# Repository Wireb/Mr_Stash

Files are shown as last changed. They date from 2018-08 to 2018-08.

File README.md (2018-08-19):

# Mr Stash
Mr Stash was a badge I built for DC26 to use for trade of other badges and SAOs. 
License is MIT so do what you want with it just don't litigate me. 

**NOTE** I screwed up and wipped my laptop hard drive before pulling the final firmware version off it. The version in this repo is from right before I left for DC26 and is missing the following items:
- LED mode that cycles though all patterns
- Bonus hidden Morse code message at high pattern offset 
- All but one vibe pattern
- Vibe mode that cycles though all patterns once
- Updated touch sensor code. Code in repo works good in my house in MN but was unusable in the dry Nevada environment. 

## InkScape
Inkscape was used for the "art" layout of the badge. This mainly consisted of the outline, Stash, motors, IR sensor locations, and eyebrows. These layers were converted into SVG files then imported into KiCad as footprints. 
The edge cuts were post processed via Perl scripts to convert it from a filled zone (KiCad 3D viewer pukes on this) to line segments. 

## KiCad
This is a KiCad 4.x project that has been updated to 5.0 so some things are a little funky. 
Note the following parts were not populated in the final design: 1x 0.1uF cap, 4x 22uF cap, 2x diodes, 1x badge bus connector, 1x SAO connector 

## mplabX
This is a mplabX 4.2 project that was upgraded mid project to 5.0. All programming / debug was done with a PicKit4 or a PicKit3 (killed my PK4 just before leaving for DC26)
The firmware source is all contained in Mr_Stash.asm (see note above about missing functions)

## documentation
This is a XLS/PDF dump of the spreadsheet documentation I was using during development. 
All the menu items and command protocol are detailed in here. 

Copyright (c) 2018 Peter Shabino

Permission is hereby granted, free of charge, to any person obtaining a copy of this hardware, software, and associated documentation files 
(the "Product"), to deal in the Product without restriction, including without limitation the rights to use, copy, modify, merge, publish, 
distribute, sublicense, and/or sell copies of the Product, and to permit persons to whom the Product is furnished to do so, subject to the 
following conditions:

The above copyright notice and this permission notice shall be included in all copies or substantial portions of the Product.

THE PRODUCT IS PROVIDED "AS IS", WITHOUT WARRANTY OF ANY KIND, EXPRESS OR IMPLIED, INCLUDING BUT NOT LIMITED TO THE WARRANTIES OF 
MERCHANTABILITY, FITNESS FOR A PARTICULAR PURPOSE AND NONINFRINGEMENT. IN NO EVENT SHALL THE AUTHORS OR COPYRIGHT HOLDERS BE LIABLE 
FOR ANY CLAIM, DAMAGES OR OTHER LIABILITY, WHETHER IN AN ACTION OF CONTRACT, TORT OR OTHERWISE, ARISING FROM, OUT OF OR IN CONNECTION 
WITH THE PRODUCT OR THE USE OR OTHER DEALINGS IN THE PRODUCT.

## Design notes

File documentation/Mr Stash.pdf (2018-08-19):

Input voltage | 3V to 4.5V | 3 AA batteries
vibration motors | 2 | PWM 7 steps + off
IR coms | 1 Tx/Rx pair | 38kHz 8N1 2994 baud
RGB leds | 4 tripplets | 2 bit PWM per color + 2 bit blink per led
Shitty addon | 1 | Wired but not populated or used in current firmware
Badgebus | 1 | Wired but not populated or used in current firmware
Micro | 1 | PIC16F15355

55 | $10.03 | $551.68 < parts only see total below for other supplies
Item | price per unit | pcs per unit | Q | extended | link Pager motors | $23.88 | 100 | $0.24 | 2 | 2 | 110 | $0.48 PIC | $26.01 | 25 | $1.04 | 1 | 1 | 55 | $1.04 | https://www.digikey.com/product-detail/en/microchip-technology/PIC16F15355-I-SS/PIC16F15355-I-SS-ND/6244561 RGB led | $79.94 | 100 | $0.80 | 4 | 4 | 220 | $3.20 | https://www.digikey.com/product-detail/en/sunled/XZMDKCBDDG45S-9/1497-1257-1-ND/5169746
googly eyes 1cm | $2.54 | 100 | $0.03 | 2 | 2 | 110 | $0.05
10.2k R | $0.60 | 100 | $0.01 | 11 | 11 | 605 | $0.07 | https://www.digikey.com/product-detail/en/yageo/RC0603FR-0710K2L/311-10.2KHRCT-ND/729830
200 R | $0.69 | 100 | $0.01 | 4 | 4 | 220 | $0.03 | https://www.digikey.com/product-detail/en/stackpole-electronics-inc/RMCF0603FT200R/RMCF0603FT200RCT-ND/1942972
100 R | $0.69 | 100 | $0.01 | 8 | 8 | 440 | $0.06 | https://www.digikey.com/product-detail/en/stackpole-electronics-inc/RMCF0603FT100R/RMCF0603FT100RCT-ND/1942965
diode | $0.92 | 10 | $0.09 | 0 | $0.00 | https://www.digikey.com/product-detail/en/taiwan-semiconductor-corporation/LS4148-L1G/LS4148L1GCT-ND/7357787 N Fet | $10.98 | 100 | $0.11 | 3 | 3 | 165 | $0.33 | https://www.digikey.com/product-detail/en/rohm-semiconductor/RK7002BMT116/RK7002BMT116CT-ND/5042538
IR led | $0.19 | 1 | $0.19 | 1 | 1 | 55 | $0.19 | https://www.digikey.com/product-detail/en/tt-electronics-optek-technology/OP181/365-1982-1-ND/5225747
20 R 1206 | $0.52 | 10 | $0.05 | 1 | 1 | 55 | $0.05 | https://www.digikey.com/product-detail/en/stackpole-electronics-inc/RNCP1206FTD20R0/RNCP1206FTD20R0CT-ND/2240645
IR sensor | $16.88 | 25 | $0.68 | 1 | 1 | 55 | $0.68 | https://www.digikey.com/product-detail/en/vishay-semiconductor-opto-division/TSSP58038/TSSP58038-ND/4695717 https://www.digikey.com/product-detail/en/vishay-semiconductor-opto-division/TSOP38538/TSOP38538-ND/4695639 Shitty conn | $5.48 | 10 | $0.55 | 1 | 0 | 0 | $0.00 | https://www.digikey.com/product-detail/en/sullins-connector-solutions/PPPC022LFBN-RC/S7105-ND/810242 Badge bus | $6.38 | 10 | $0.64 | 1 | 0 | 0 | $0.00 | https://www.digikey.com/product-detail/en/amphenol-fci/10120045-401LF/609-5015-1-ND/5731726
battery holder | $0.50 | 1 | $0.50 | 1 | 1 | 55 | $0.50
fur | $26.95 | 50 | $0.54 | 1 | 1 | 55 | $0.54 | https://www.etsy.com/listing/593695207/rainbow-tie-dye-fur-rainbow-faux-fur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
0.1uF 0805 | $2.62 | 100 | $0.03 | 2 | 1 | 55 | $0.03 | https://www.digikey.com/product-detail/en/yageo/CC0805ZRY5V9BB104/311-1361-1-ND/2103145
22uF 0805 | $14.52 | 100 | $0.15 | 5 | 1 | 55 | $0.15 | https://www.digikey.com/product-detail/en/samsung-electro-mechanics/CL21A226MOCLRNC/1276-6780-1-ND/5961639 PCBs | $132.92 | 50 | $2.66 | 1 | 1 | 55 | $2.66
714.56 | 54 | 13.23259259 Proto PCBs | 39.75 | < OSH park digikey parts | 32.17 Digikey parts | $377.22 PCBs | $132.92
stickers | $9.50 | < used for masking during spray gluing
super 77 | $10.78 Pager motors | $23.88
googly eyes 1cm | $2.54
fur | $26.95 Double stick tape | $4.00 < used for attaching the battery holders more eyes | $1.01 more pagers | $3.84 Battery holders | $50.00 Masking tape | ? | < used for masking during spray gluing Lanyards | ? | < lost the invoice
Labor | ? | < way too much :) all hand assembled including parts placement.

Catagory | item | notes | priority | Status | more notes | Items marked lost were in the final firmware on the badges. But I forgot to copy the source files up before wiping my laptop post defcon :(
IR | becon | | | done
IR | direct remote | done | ish continous button detection is really iffy could be better
IR | set mode reg | | | done | 8 bits mode
IR | vibe control | | | done
IR | set custom color | done | 12 bit select. first 2 bits selects the led to update, next bit not used, then 8 bits led value, then 1 bit not used.
Leds | bin count | multi color | | done
Leds | bin count | custom color | | done
Leds | bin count | bit order swapped | | done
Leds | cycle | walk though all the options... | | Lost
Leds | Fixed color | | | done
Leds | Larson | custom color | done | Use values from fixed color led 4 and 3 for the main dot and the trailer
Leds | Larson | 2 swipe color change | | done
Leds | Larson | Full rainbow per dot | done | first dot as cycled. Second dot previous cycle and 0x15
Leds | rainbow | left | | done
Leds | rainbow | right | | done
Leds | Random LFSR | | | done
Leds | Larson | 1 swipe color change | | done
other | save to flash | | | done
vibe | base code | | | done
Leds | morse code | ride me | | done
Leds | morse code | bounus | Lost | hidden message at upper offset
other | beacon disable | done | just disable rcv not sends. Ok if reset on use of remote control reg..
vibe | more patterns | | | Lost
vibe | cycle | | | Lost

Bit order reading leds left to right [b = 11, g = 10, r = 9][b = 8, g = 7, r = 6][b = 5, g = 4, r = 3] [b = 2, g = 1, r = 0]

rmt mode register (8 bit) function | width | notes
ok | y | 0 display mode | 8 default reg for all unimplemented values
ok | | | 0 rainbow left
ok | | | 1 rainbow right
ok | | | 2 static custom color (pick color with mode reg 2 per led and blink setting with mode reg 3 per led)
ok | | | 3 LFSR blink (as random as I can get)
ok | | | 4 Larson scanner using custom colors (right LED leading dot, middle right trailing dot)
ok | | | 5 Larson scanner RGB 1 direction per color
ok | | | 6 Larson scanner RGB 2 directions per color
ok | | | 7 Larson scanner Rainbow per led
ok | | | 8 Ride me custom color (right LED)
ok | | | 9 Ride me rainbow led
ok | a | Count LSB L custom colors
ok | b | Count LSB L rainbow same per set
ok | c | Count LSB L rainbow different per led on
ok | d | Count LSB R custom colors
ok | e | Count LSB R rainbow same per set
ok | f | Count LSB R rainbow different per led on
lost | | | 10 cycle through all above
lost | AA | you are dedicated rainbow
ok | y | 1 display speed | 12 Sets the clock multiplyer for how fast the animation delay loops run
ok | y | 2 custom colors | 24 6 bits per led
ok | y | 3 custom blink | 8 2 bits per led
ok | y | 4 vibe pattern | 8 Selecting a pattern will start a run of that pattern when final set is pressed
ok | | | 0 simple up down 1 motor no stop
lost | | | 1 simple up down 1 motor with stop
lost | | | 2 ramp up motor 1, then motor 2, motor 1 down, motor 2 down, stop
lost | | | 3 ramp up cliff
lost | | | 4 ramp down cliff
lost | | | 5 ping pong
lost | | | 6 ping off pong off
lost | | | 7 ramp bounce
lost | | | 8 ride me
lost | | | 9 oh yea
lost | a | twinlke
lost | b | cycle through all above
ok | n | 5 vibe loop cnt | 8 Above pattern will repeat this many times after the inital run (0 not valid and will run the loop once)

| Bit order reading leds left to right [b = 11, g = 10, r = 9][b = 8, g = 7, r = 6][b = 5, g = 4, r = 3] [b = 2, g = 1, r = 0]
rmt | mode register (8 bit) | function | width | notes
ok | y | | 6 vibe speed | 12 Sets the clock multiplyer for how fast the vibe loops run
ok | n | | 7 save settings | 0 second set saves var when chosen
ish | y | | 8 direct remote | 0 after second set A / B buttons trigger remote motor set exits
ok | - | | 9 rmt display mode | 8 changes all remote badges to chosen pattern that are in IR range.
ok | - | A | rmt speed l | change all remote badges in IR range LSB of animation speed
ok | - | B | rmt speed h | change all remote badges in IR range MSB of animation speed (masked to 4 lsb for 12 bits total)
ok | - | C | rmt LED1 | change all remote badges in IR range custom LED1 (2 bits blink, 2 bits blue, 2 bits green, 2 bits red - bit order 7 - 0)
ok | - | D | rmt LED2 | change all remote badges in IR range custom LED2
ok | - | E | rmt LED3 | change all remote badges in IR range custom LED3
ok | - | F | rmt LED4 | change all remote badges in IR range custom LED4
ok | - | | 10 rmt vibe | change all remote badges in IR range set vibe pattern and start a single cycle
ok | - | | 11 rmt vibe spd l | change all remote badges in IR range LSB of vibe speed
ok | - | | 12 rmt vibe spd h | change all remote badges in IR range MSB of vibe speed (masked to 4 lsb for 12 bits total)
ok | | | 13 beacon rcv off | bit 1 enables / disable the beacon vibe pulse. Rest to on after direct remote use

### IR 8N1 2994 baud

### frame structure

M | S | [cmd] | [badge id] | [data] | [checksum]
0x4D | 0x53 | .. | .. | .. | ..
1001101 | 1010011
The checksum should be set such when all bytes of the frame are added to gether and ANDed with 0xFF the result is 0
Command | data | notes
| 0 not used | if the badge ID rcvd is not = to this badge pulse M2
| 1 bit 0 = MT1, bit 1 = MT2
| 2 reg value | set badge display mode to this value
| 3 reg value | set LSB of animation speed
| 4 reg value | set MSB of animation speed (masked to 4 lsb for 12 bits total)
| 5 reg value | set custom LED1 (2 bits blink, 2 bits blue, 2 bits green, 2 bits red - bit order 7 - 0)
| 6 reg value | set custom LED2
| 7 reg value | set custom LED3
| 8 reg value | set custom LED4
| 9 reg value | set and start a single cycle of vibe pattern
A | reg value | set LSB of vibe speed
B | reg value | set MSB of vibe speed (masked to 4 lsb for 12 bits total)

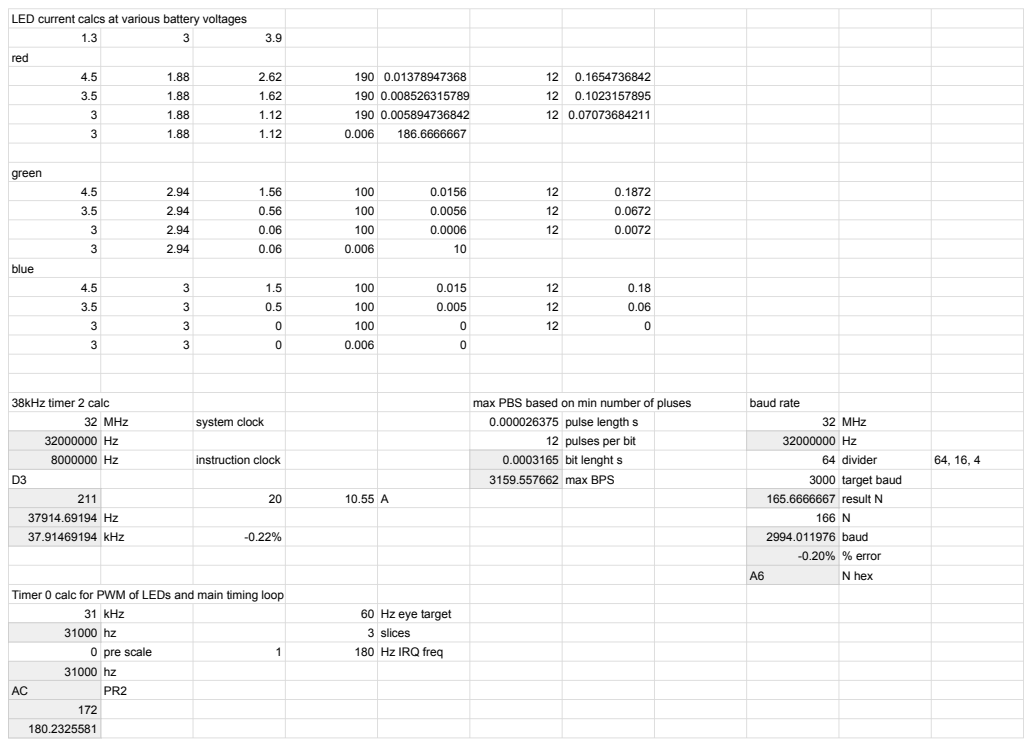
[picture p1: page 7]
red; green; blue; 38kHz timer 2 calc; max PBS based on min number of pluses; baud rate; 32 MHz; system clock; 0.000026375 pulse length s; result N; kHz; baud; % error; N hex; 31 kHz; 60 Hz eye target; 3 slices; 0 pre scale; 180 Hz IRQ freq

LED current calcs at various battery voltages

32000000 8000000 | Hz 12 pulses per bit | 32000000 | Hz
Hz instruction clock | 0.0003165 | bit lenght s 64 divider 64, 16, 4

D3 | 3159.557662 | max BPS 3000 target baud

Timer 0 calc for PWM of LEDs and main timing loop

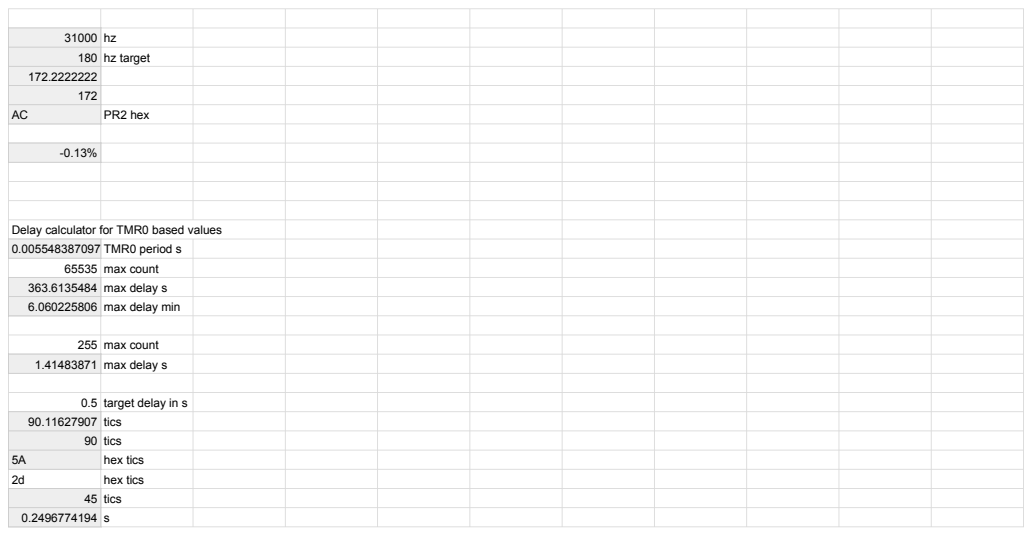
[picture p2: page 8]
65535 max count; max delay s; max delay min; 255 max count; tics; hex tics

31000 | hz
180 | hz target

172.2222222 172 AC | PR2 hex

Delay calculator for TMR0 based values
0.005548387097 TMR0 period s

0.5 target delay in s

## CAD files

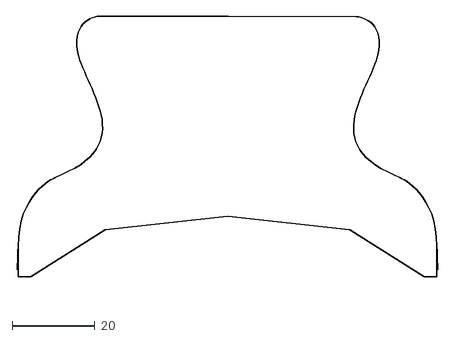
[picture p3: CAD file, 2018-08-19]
InkScape/Mr_Stash-cuts.dxf
102.4 x 68.4

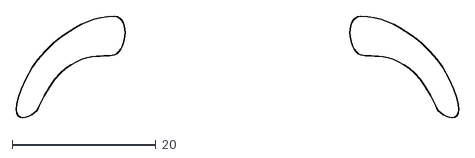
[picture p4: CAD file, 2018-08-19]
InkScape/Mr_Stash-silk.dxf
61.6 x 14.1

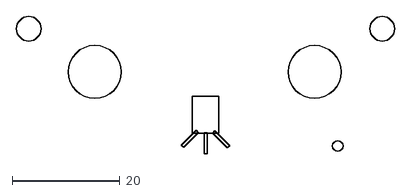
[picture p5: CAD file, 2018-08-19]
InkScape/Mr_Stash-user.dxf
70.2 x 25.4

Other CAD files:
InkScape/Mr_Stash-fmask.dxf

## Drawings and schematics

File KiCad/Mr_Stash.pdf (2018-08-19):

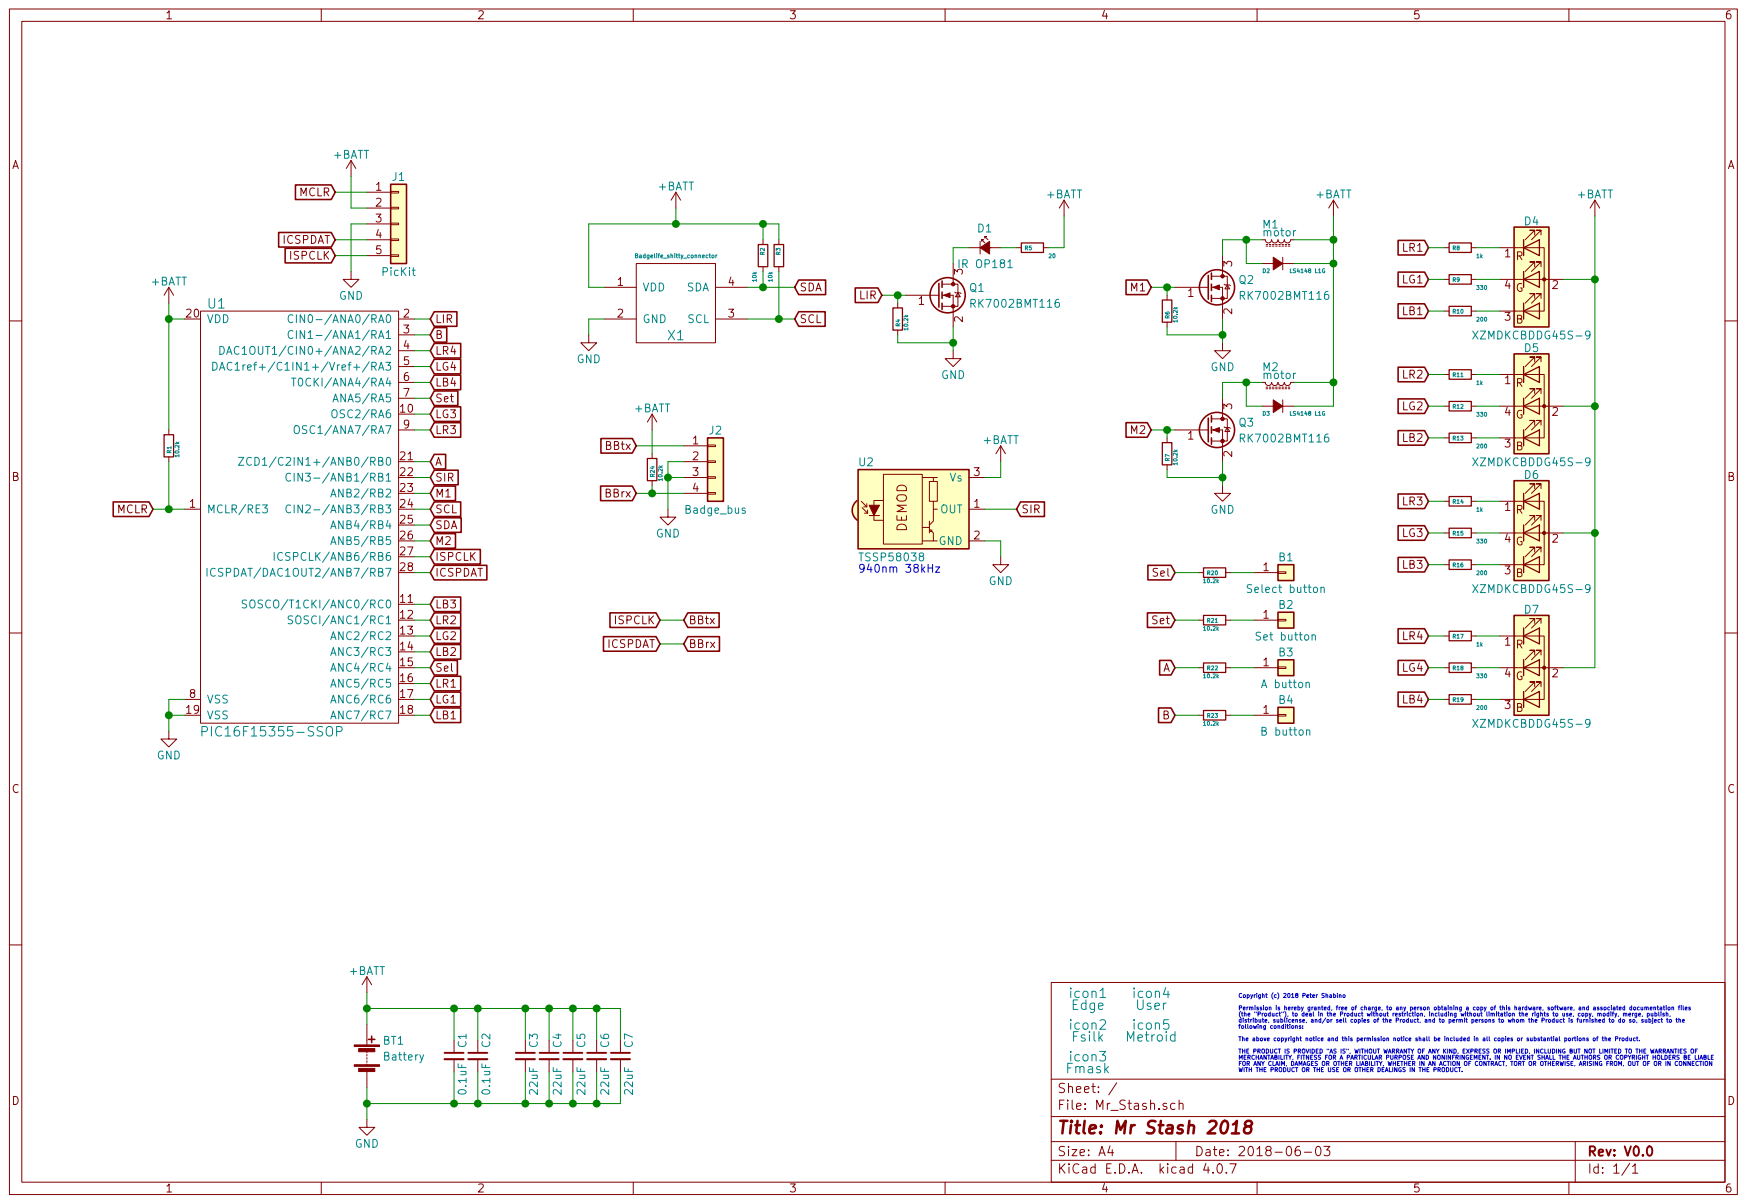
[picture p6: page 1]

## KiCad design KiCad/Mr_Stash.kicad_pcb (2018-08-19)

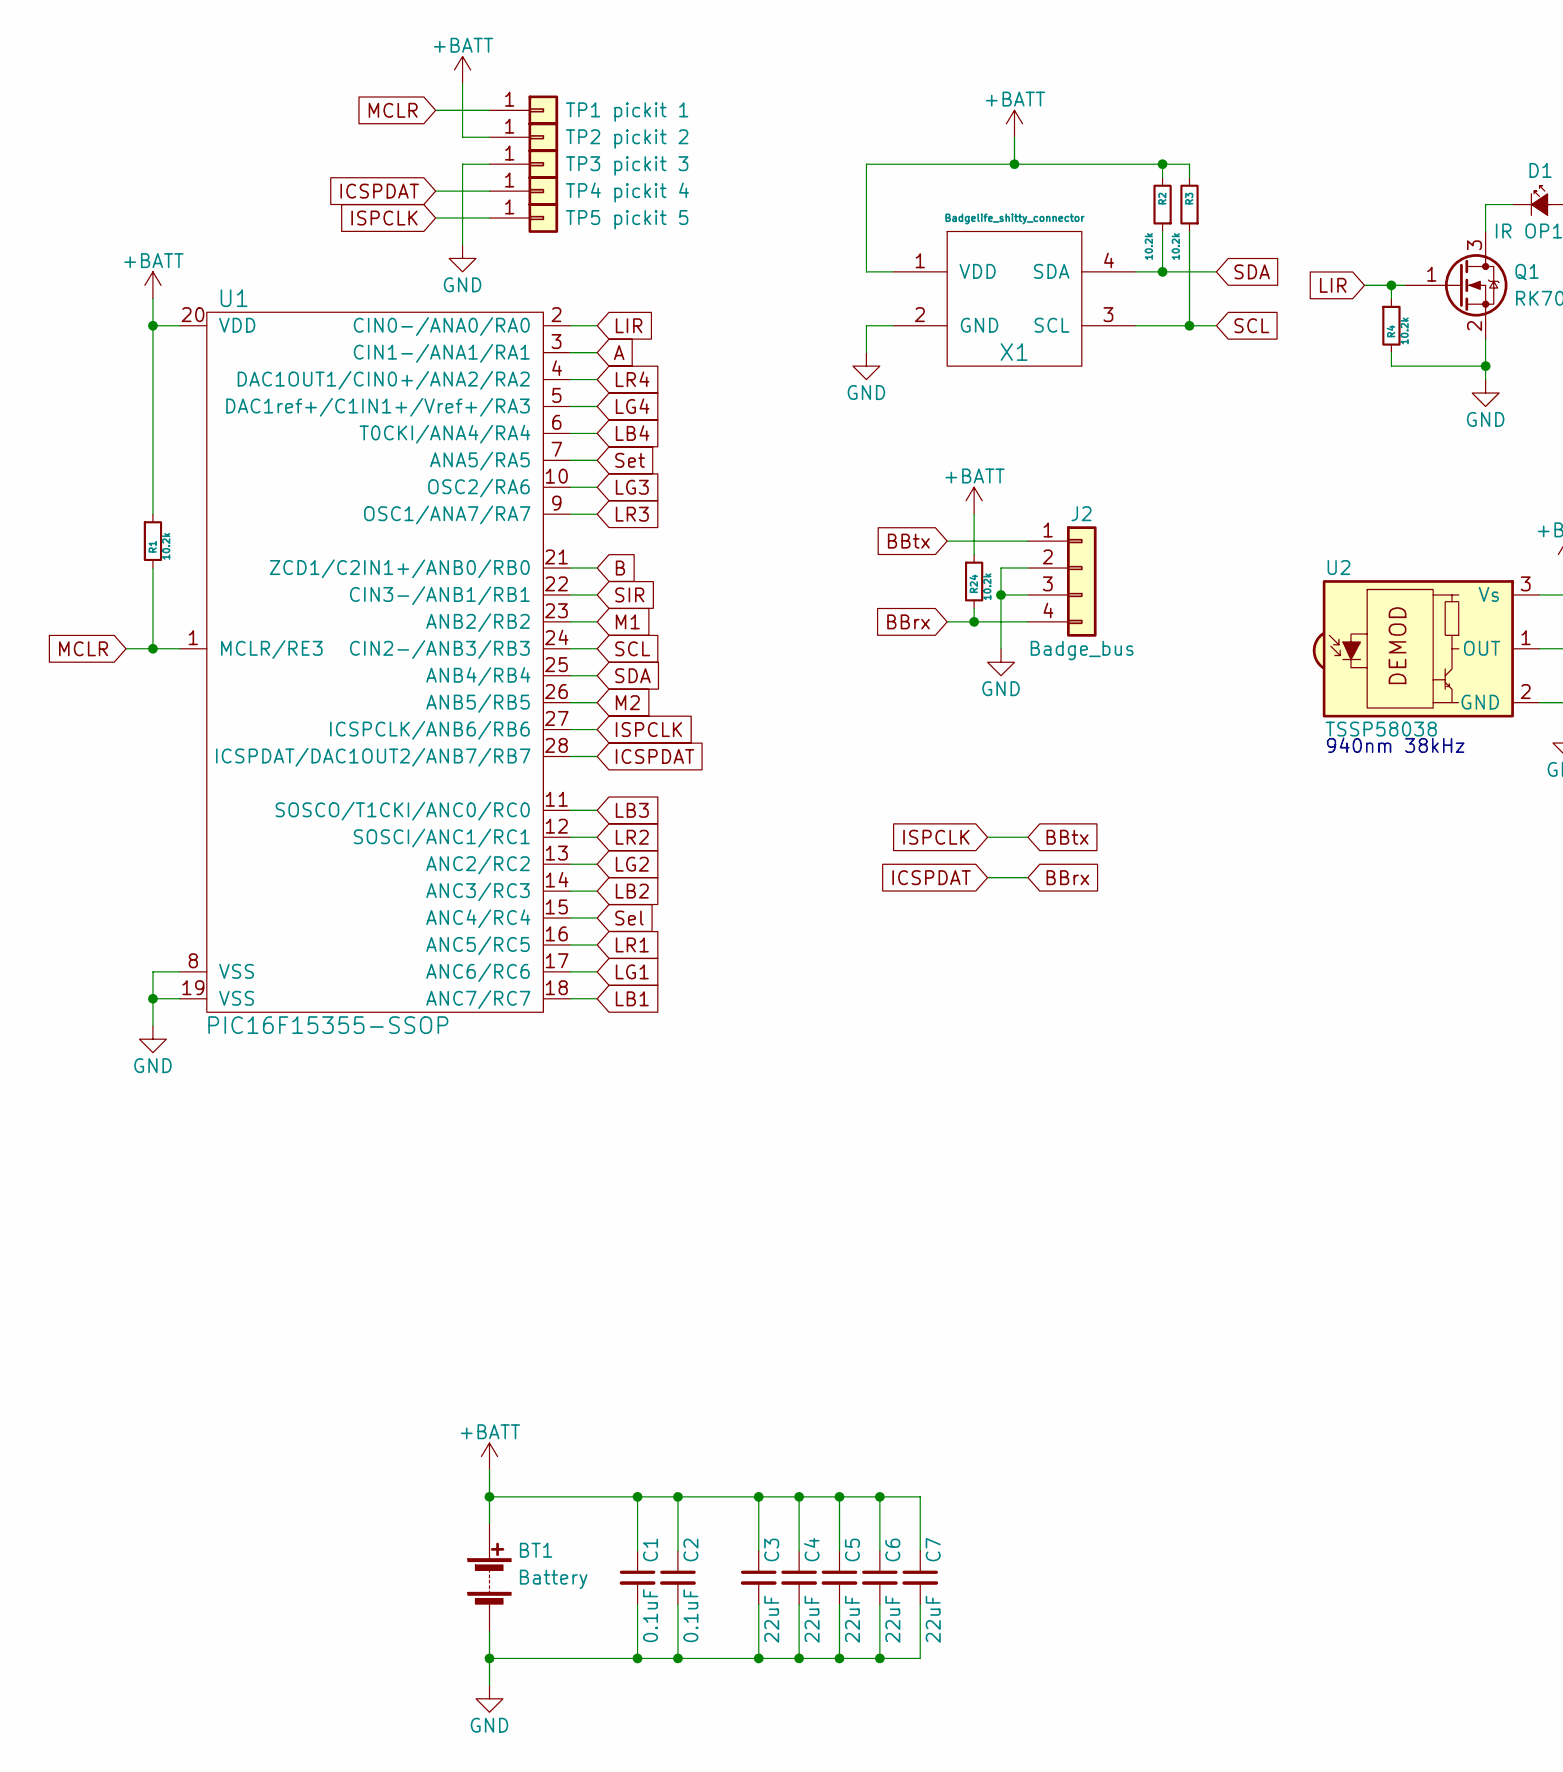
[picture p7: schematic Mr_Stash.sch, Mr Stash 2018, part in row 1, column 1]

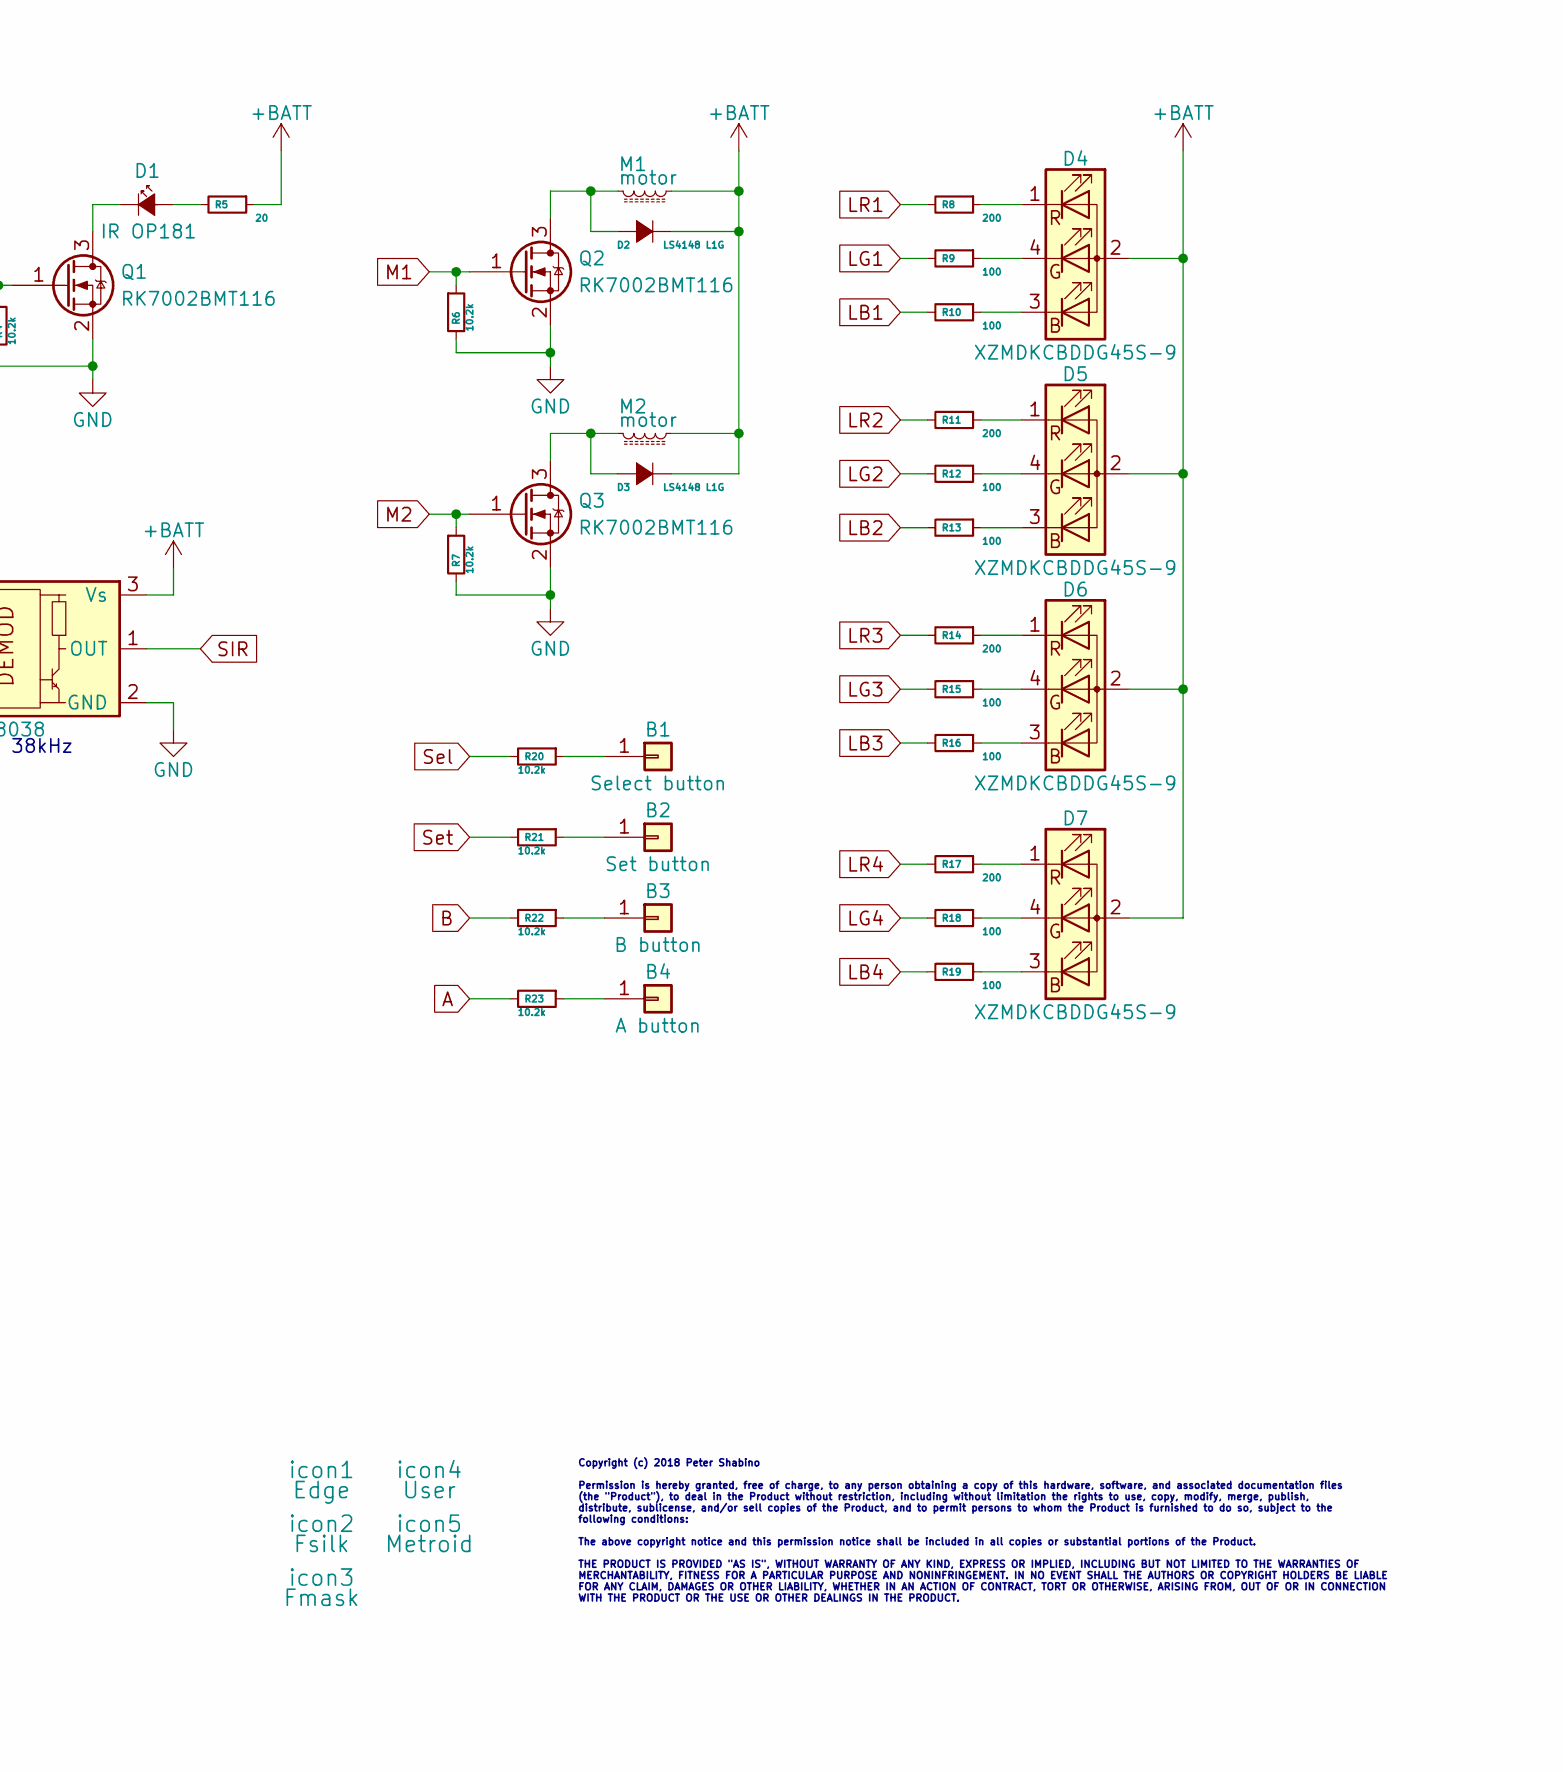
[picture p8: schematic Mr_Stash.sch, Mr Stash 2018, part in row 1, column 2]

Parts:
B1: Select button; blank_button_7.5mm
B2: Set button; blank_button_7.5mm
B3: A button; blank_button_7.5mm
B4: B button; blank_button_7.5mm
BT1: Battery; Keystone_3_AA_battery_holder
C1, C2: 0.1uF; C_0805
C3, C4, C5, C6, C7: 22uF; C_0805
D1: IR OP181; OP181_TT_electronics_IR
D2, D3: LS4148 L1G; SOD-80V-LS34
D4, D5, D6, D7: XZMDKCBDDG45S-9; XZMDKCBDDG45S-9-3mm-hole
J2: Badge_bus; 10120045-40-LF
M1, M2: motor; Pager_motor_10mm_smt
Q1, Q2, Q3: RK7002BMT116; SOT-23
R1, R2, R3, R4, R6, R7, R20, R21, R22, R23, R24: 10.2k; R_0603
R5: 20; R_1206
R8, R11, R14, R17: 200; R_0603
R9, R10, R12, R13, R15, R16, R18, R19: 100; R_0603
TP1: pickit 1; 80mill_sqr_test_point
TP2: pickit 2; 80mill_test_point
TP3: pickit 3; 80mill_test_point
TP4: pickit 4; 80mill_test_point
TP5: pickit 5; 80mill_test_point
U1: PIC16F15355-SSOP; SSOP-28_5.3x10.2mm_Pitch0.65mm
U2: TSSP58038; TSSP58038_custom_45_SMT
X1: Badgelife_shitty_connector; Badgelife-Shitty-2x2
icon1: Edge; mr-stash_cuts
icon2: Fsilk; mr-stash_silk
icon3: Fmask; mr-stash_fmask
icon4: User; mr-stash_user
icon5: Metroid; metroid

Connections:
+BATT: BT1.1 (+), C1.1, C2.1, C3.1, C4.1, C5.1, C6.1, C7.1, D2.1 (K), D3.1 (K), D4.2 (A), D5.2 (A), D6.2 (A), D7.2 (A), M1.1, M2.1, R1.1, R2.2, R3.2, R5.1, R24.1, TP2.1, U1.20 (VDD), U2.3 (Vs), X1.1 (VDD)
A: R22.2, U1.21 (ZCD1/C2IN1+/ANB0/RB0)
B: R23.2, U1.3 (CIN1-/ANA1/RA1)
BBrx: J2.4, R24.2, TP4.1, U1.28 (ICSPDAT/DAC1OUT2/ANB7/RB7)
BBtx: J2.1, TP5.1, U1.27 (ICSPCLK/ANB6/RB6)
GND: BT1.2 (-), C1.2, C2.2, C3.2, C4.2, C5.2, C6.2, C7.2, J2.2, J2.3, Q1.2 (S), Q2.2 (S), Q3.2 (S), R4.2, R6.2, R7.2, TP3.1, U1.8 (VSS), U1.19 (VSS), U2.2 (GND), X1.2 (GND)
LB1: R10.2, U1.18 (ANC7/RC7)
LB2: R13.2, U1.14 (ANC3/RC3)
LB3: R16.2, U1.11 (SOSCO/T1CKI/ANC0/RC0)
LB4: R19.2, U1.6 (T0CKI/ANA4/RA4)
LG1: R9.2, U1.17 (ANC6/RC6)
LG2: R12.2, U1.13 (ANC2/RC2)
LG3: R15.2, U1.10 (OSC2/RA6)
LG4: R18.2, U1.5 (DAC1ref+/C1IN1+/Vref+/RA3)
LIR: Q1.1 (G), R4.1, U1.2 (CIN0-/ANA0/RA0)
LR1: R8.2, U1.16 (ANC5/RC5)
LR2: R11.2, U1.12 (SOSCI/ANC1/RC1)
LR3: R14.2, U1.9 (OSC1/ANA7/RA7)
LR4: R17.2, U1.4 (DAC1OUT1/CIN0+/ANA2/RA2)
M1: Q2.1 (G), R6.1, U1.23 (ANB2/RB2)
M2: Q3.1 (G), R7.1, U1.26 (ANB5/RB5)
MCLR: R1.2, TP1.1, U1.1 (MCLR/RE3)
unnamed: B1.1, R20.1
unnamed: B2.1, R21.1
unnamed: B3.1, R22.1
unnamed: B4.1, R23.1
unnamed: D1.1 (K), Q1.3 (D)
unnamed: D1.2 (A), R5.2
unnamed: D2.2 (A), M1.2, Q2.3 (D)
unnamed: D3.2 (A), M2.2, Q3.3 (D)
unnamed: D4.1 (RK), R8.1
unnamed: D4.3 (BK), R10.1
unnamed: D4.4 (GK), R9.1
unnamed: D5.1 (RK), R11.1
unnamed: D5.3 (BK), R13.1
unnamed: D5.4 (GK), R12.1
unnamed: D6.1 (RK), R14.1
unnamed: D6.3 (BK), R16.1
unnamed: D6.4 (GK), R15.1
unnamed: D7.1 (RK), R17.1
unnamed: D7.3 (BK), R19.1
unnamed: D7.4 (GK), R18.1
SCL: R3.1, U1.24 (CIN2-/ANB3/RB3), X1.3 (SCL)
SDA: R2.1, U1.25 (ANB4/RB4), X1.4 (SDA)
SIR: U1.22 (CIN3-/ANB1/RB1), U2.1 (OUT)
Sel: R20.2, U1.15 (ANC4/RC4)
Set: R21.2, U1.7 (ANA5/RA5)

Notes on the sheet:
940nm 38kHz
Copyright (c) 2018 Peter Shabino Permission is hereby granted, free of charge, to any person obtaining a copy of this hardware, software, and associated documentation files (the "Product"), to deal in the Product without restriction, including without limitation the rights to use, copy, modify, mer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

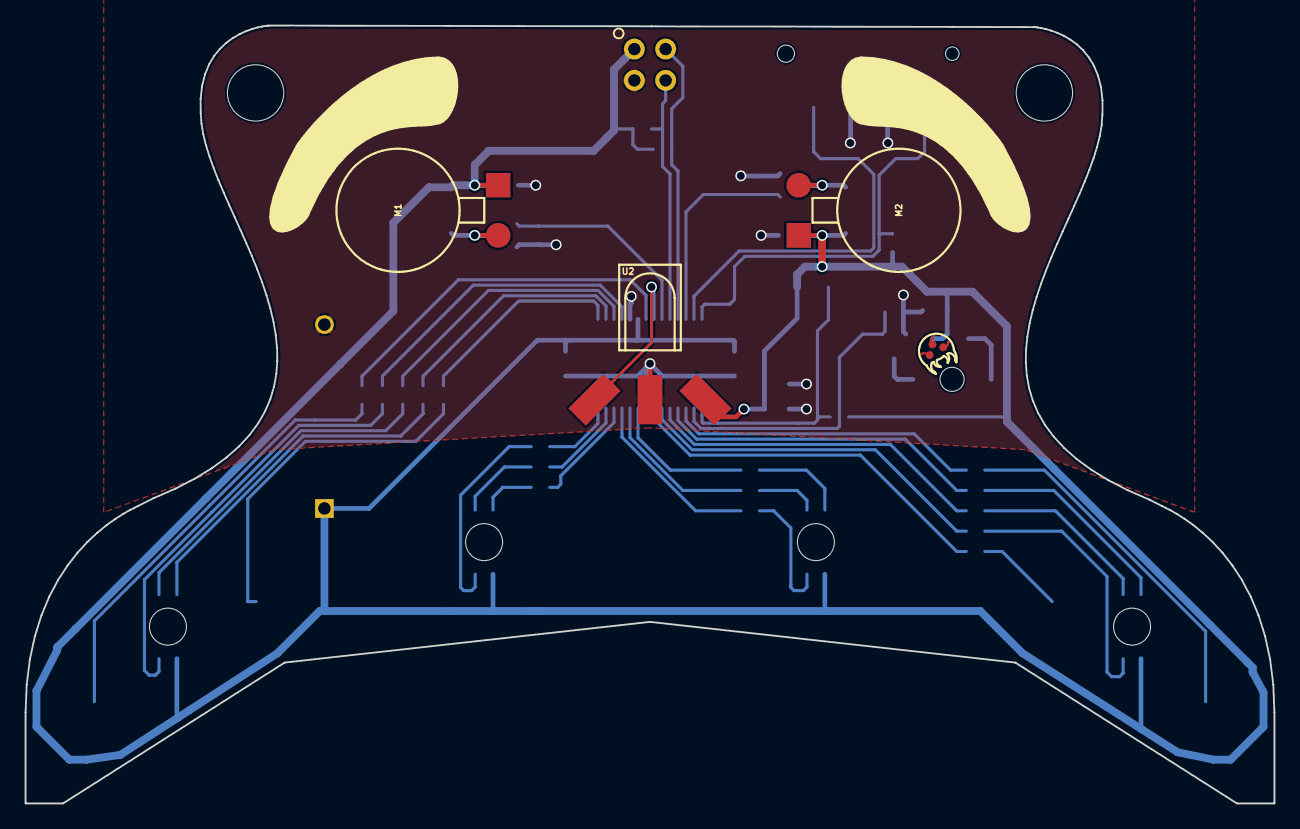
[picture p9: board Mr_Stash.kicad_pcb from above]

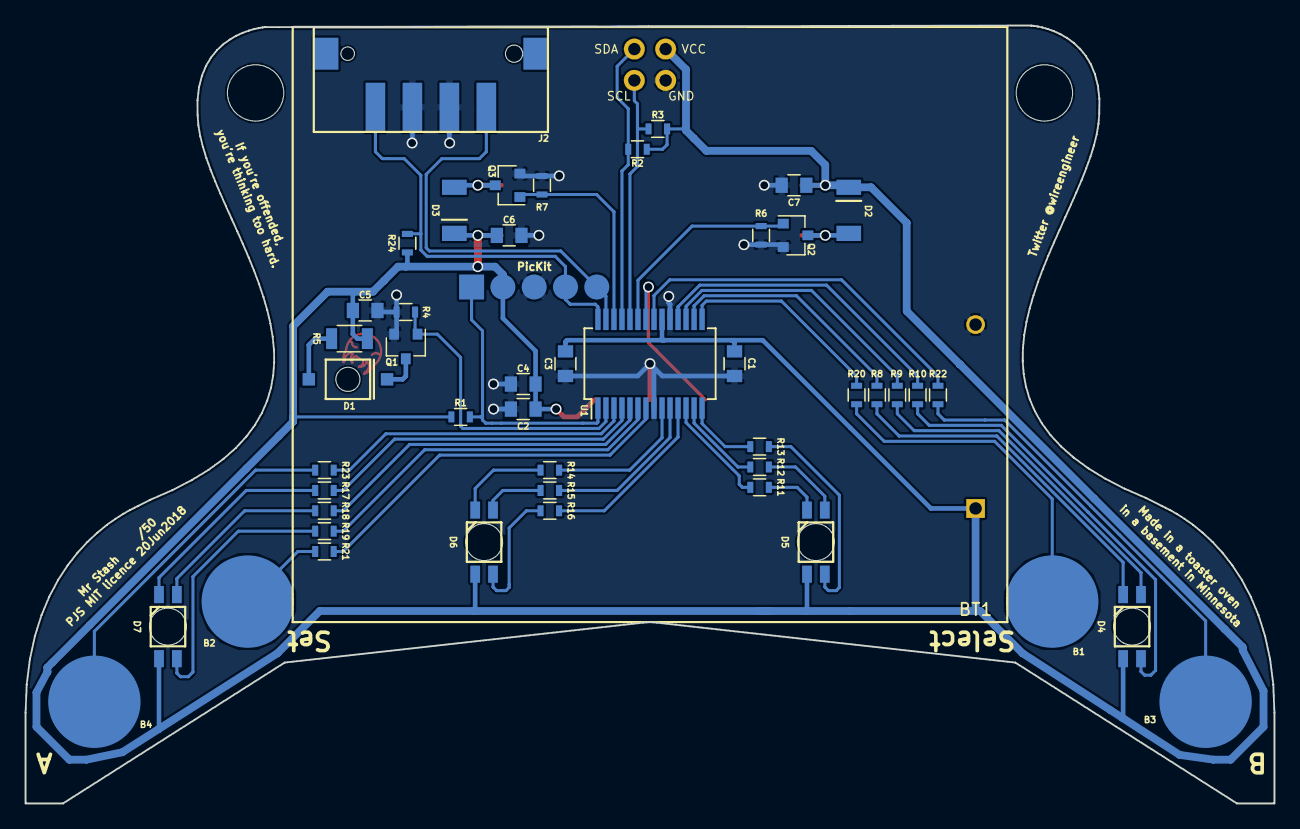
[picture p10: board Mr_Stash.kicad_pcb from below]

Board: 2 copper layers, 101.3 x 63.1 mm, 62 parts (53 on the bottom side), 47 nets.

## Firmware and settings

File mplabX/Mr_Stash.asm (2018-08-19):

;#########################################################################################################################################################
;Copyright (c) 2018 Peter Shabino
;
;Permission is hereby granted, free of charge, to any person obtaining a copy of this hardware, software, and associated documentation files 
;(the "Product"), to deal in the Product without restriction, including without limitation the rights to use, copy, modify, merge, publish, 
;distribute, sublicense, and/or sell copies of the Product, and to permit persons to whom the Product is furnished to do so, subject to the 
;following conditions:
;
;The above copyright notice and this permission notice shall be included in all copies or substantial portions of the Product.
;
;THE PRODUCT IS PROVIDED "AS IS", WITHOUT WARRANTY OF ANY KIND, EXPRESS OR IMPLIED, INCLUDING BUT NOT LIMITED TO THE WARRANTIES OF 
;MERCHANTABILITY, FITNESS FOR A PARTICULAR PURPOSE AND NONINFRINGEMENT. IN NO EVENT SHALL THE AUTHORS OR COPYRIGHT HOLDERS BE LIABLE 
;FOR ANY CLAIM, DAMAGES OR OTHER LIABILITY, WHETHER IN AN ACTION OF CONTRACT, TORT OR OTHERWISE, ARISING FROM, OUT OF OR IN CONNECTION 
;WITH THE PRODUCT OR THE USE OR OTHER DEALINGS IN THE PRODUCT.
;#########################################################################################################################################################
; 09Jun18 V0 PJS New
; 08Jul18 V3 PJS 8 and 12 bit menue entry working 
; 15Jul18 V4 PJS Custom colors fully working (including blink), custom Larson scanner working, Split code over 3 pages of flash (4th rsvd for vibe if needed) 
; 01Aug18 V5 PJS Saving of setting to eeprom working and "direct remote" code mostly working
	
#define CODE_VER 0x05
#define	CODE_VER_STRING "Peter Shabino 01Aug18 code for Mr Stash 2018 V5 www.wire2wire.org!" ;Just in ROM !!! update vars below with true level!!
ver_a	equ	0x33
ver_b	equ	0x00
ver_c	equ	0x00
ver_d	equ	0x00
	
; NOTES
; SAF is high endurance flash (128 words) at the end of flash. Not usable as program space when enabled in config words 

;****************************************************************************************
; port list [SSOP28]
; Vss(8,19)
; Vdd(20)
; RA0(2)	LIR
; RA1(3)	B
; RA2(4)	LR4
; RA3(5)	LG4
; RA4(6)	LB4
; RA5(7)	Set
; RA6(10)	LG3
; RA7(9)	LR3
; RB0(21)	A
; RB1(22)	SIR
; RB2(23)	M1
; RB3(24)	SCL
; RB4(25)	SDA
; RB5(26)	M2
; RB6(27)	[ISPCLK] BBtx
; RB7(28)	[ICSPDAT] BBrx
; RC0(11)	LB3
; RC1(12)	LR2
; RC2(13)	LG2
; RC3(14)	LB2
; RC4(15)	Sel
; RC5(16)	LR1
; RC6(17)	LG1
; RC7(18)	LB1
; RE3(1)	[MCLR]	
;****************************************************************************************

	
; PIC16F15355 Configuration Bit Settings
#include "p16f15355.inc"
; CONFIG1
; __config 0xFF8C
 __CONFIG _CONFIG1, _FEXTOSC_OFF & _RSTOSC_HFINT32 & _CLKOUTEN_OFF & _CSWEN_ON & _FCMEN_ON
; CONFIG2
; __config 0xF7FD
 __CONFIG _CONFIG2, _MCLRE_ON & _PWRTE_ON & _LPBOREN_OFF & _BOREN_ON & _BORV_LO & _ZCD_OFF & _PPS1WAY_OFF & _STVREN_ON
; CONFIG3
; __config 0xFF9F
 __CONFIG _CONFIG3, _WDTCPS_WDTCPS_31 & _WDTE_OFF & _WDTCWS_WDTCWS_7 & _WDTCCS_SC
; CONFIG4
; __config 0xDFEF
 __CONFIG _CONFIG4, _BBSIZE_BB512 & _BBEN_OFF & _SAFEN_ON & _WRTAPP_OFF & _WRTB_OFF & _WRTC_ON & _WRTSAF_OFF & _LVP_OFF
; CONFIG5
; __config 0xFFFE
 __CONFIG _CONFIG5, _CP_ON	
 
 
;#define __LED_TEST_MODE__
 
;------------------
; constants
;------------------	
; Default USER ID to load
UserID  code 0x8000
	dw 0x3FFF
    ;dw 0x3F00	

; test code for load from flash storage	/ test modes
;Settings  code 0x1F80
;	dw 0x3F03	
;	dw 0x3F0C
;	dw 0x3F30
;	dw 0x3FC3	
;	dw 0x3F06	
;	dw 0x3F20	
;	dw 0x3F00	

	
START_OF_REGS			equ 0x65			; constant to first reg that should be restored from flash assumes 0x6F is the end. 		
IR_PULSE_WIDTH			equ 0x35			; pulse width set to 10% (0x69 = 50%, 0x35 = 25%, 0x15 = 10%, 0x0A = 5%)
IR_B_ON_PWM				equ 0xFF
IR_B_ON_TIME			equ 0x12			; on time for beacon buzzer 
IR_DIRECT_RMT_ON_PWM	equ 0xFF
IR_DIRECT_RMT_ON_TIME	equ 0x12			; on time for direct remote buzzer (on till next IR input cycle...) 
TOUCH_TRIP				equ 0x50			; trip point delta on ADC value (tune to prevent false touches)
BUTTON_DEBOUNCE			equ 0x02			; how many cycles of no press to wait before taking next entry (larger = less twitchy but slower max updates)
BEACON_TIME_L			equ 0xF6			; delay between beacon sends
BEACON_TIME_H			equ 0x04		
;------------------
; vars (0x20 - 0x6f) bank 0
;------------------
LED1			equ 0x20			; 0-1 red, 2-3 green, 4-5 blue, 6-7 blink
LED2			equ 0x21			; 0-1 red, 2-3 green, 4-5 blue, 6-7 blink
LED3			equ 0x22			; 0-1 red, 2-3 green, 4-5 blue, 6-7 blink
LED4			equ 0x23			; 0-1 red, 2-3 green, 4-5 blue, 6-7 blink
led_seq			equ 0x24
porta_temp		equ 0x25		
portc_temp		equ 0x26		
blink_seq		equ 0x27
beacon_timer_l	equ 0x28
beacon_timer_h	equ 0x29
ir_status		equ 0x2A			; 
badge_id		equ 0x2B
ir_cmd			equ 0x2C		
ir_data			equ 0x2D
ir_chksum		equ 0x2E
ir_tx_seq		equ 0x2F	
ir_rx_seq		equ 0x30
ir_rx_chksum	equ 0x31
ir_rx_data		equ 0x32
ir_rx_id		equ 0x33
ir_rx_cmd		equ 0x34					
temp			equ 0x35
beacon_b_timer	equ 0x36
mode_ctl		equ 0x37
no_press_cnt	equ 0x38
led_timer_low	equ 0x39
led_timer_high	equ 0x3A
sequence		equ 0x3B
mode_reg		equ 0x3C
led_display_seq	equ 0x3D		
temp2			equ 0x3E	
temp3			equ 0x3F
call_temp		equ	0x40
direct_m1_timer	equ 0x41
direct_m2_timer	equ 0x42
ir_data_temp	equ	0x43	
vibe_cycle		equ 0x44
vibe_timer_low	equ 0x45
vibe_timer_high equ 0x46	
vibe_sequence	equ 0x47
vibe_stop		equ 0x48
vibe_temp		equ 0x49
vibe_subloop	equ 0x4A
		
		
; UPDTATE START_OF_REGS in constants if you add any more saved vars to this section!!!	
	
vibe_speed_l	equ	0x65
vibe_speed_h	equ	0x66
vibe_rpt		equ 0x67	
vibe_mode 		equ	0x68	
cust_led4		equ	0x69	
cust_led3		equ	0x6A		
cust_led2		equ	0x6B	
cust_led1		equ	0x6C		
led_mode_reg	equ 0x6D
speed_low		equ 0x6E		
speed_high		equ 0x6F		

;------------------
; vars (0xA0 - 0xef) bank 1
;------------------
adc_seq			equ 0xA0
button1_cur		equ 0xA1
button2_cur		equ 0xA2
button3_cur		equ 0xA3
button4_cur		equ 0xA4
button1_last	equ 0xA5
button2_last	equ 0xA6
button3_last	equ 0xA7
button4_last	equ 0xA8

;------------------
; vars (0x120 - 0x16f) bank 2
;------------------
LFSR_0			equ	0x120
LFSR_1			equ	0x121
LFSR_2			equ	0x122
LFSR_3			equ	0x123

;------------------
; vars (0x1A0 - 0x1ef) bank 3
;------------------

;------------------
; vars (0x220 - 0x26f) bank 4
;------------------

;------------------
; vars (0x2A0 - 02xef) bank 5
;------------------
 
;------------------
; vars (0x320 - 0x36f) bank 6 (55 part only 0x320 to 0x32F on 54 part) 
;------------------
		
;------------------
; vars (0x3A0 - 0x3ef) bank 7 (55 part only)
;------------------

;------------------
; vars (0x420 - 0x46f) bank 8 (55 part only) 
;------------------

;------------------
; vars (0x4A0 - 0x4ef) bank 9 (55 part only)
;------------------

;------------------
; vars (0x520 - 0x56f) bank 10 (55 part only) 
;------------------
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

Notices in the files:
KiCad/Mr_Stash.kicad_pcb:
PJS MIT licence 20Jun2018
